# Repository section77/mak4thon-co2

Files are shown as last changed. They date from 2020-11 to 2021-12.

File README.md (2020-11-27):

# Klassenzimmer Modul

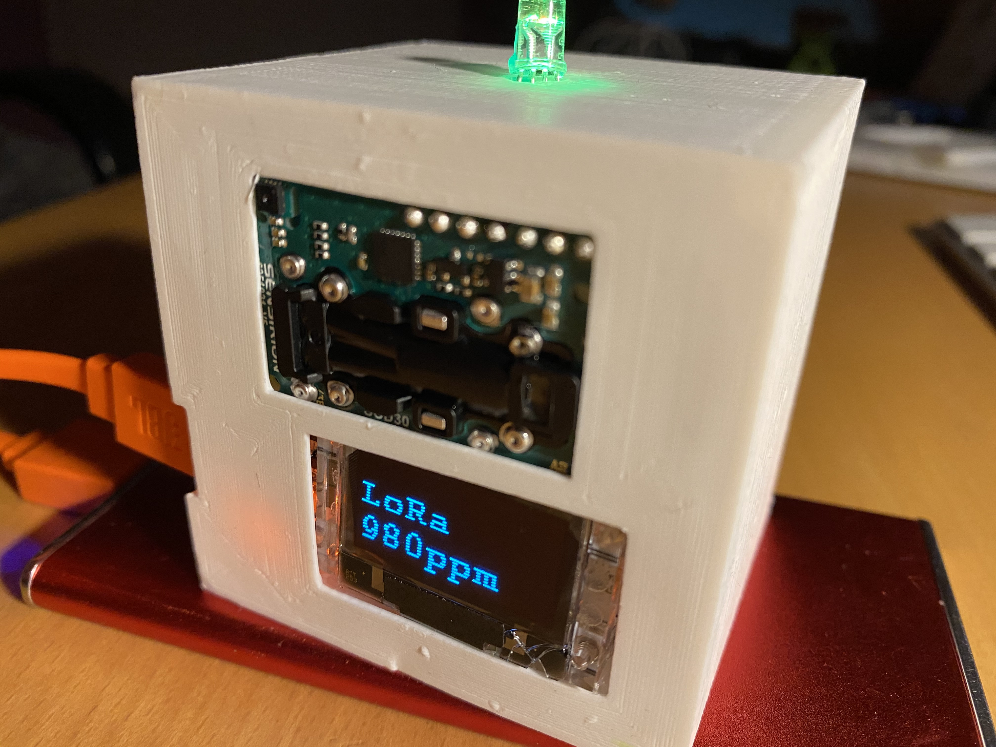
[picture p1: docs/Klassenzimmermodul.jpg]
Klassenzimmer Modul


## Hardware:
- Heltec WiFi Lora 32 V2 mit OLED
- SCD30 CO2 Sensor
- RGB LED zur Signalisierung der CO2 Konzentration (rot, gelb, grün)
- OLED Display zur numerischen Anzeige CO2 Konzentration, Luftfeuchtigkeit und Temperatur sowie WiFi oder LoRa Status

## Funktion:
  CO2, Luftfeuchtigkeit und Temperatur aus dem SCD30 lesen und
  auf dem OLED darstellen. Grenzwertüberschreitung an der RGB LED anzeigen.
  Digitale Werte über WiFi nach volkszaehler.org schreiben oder über LoRa
  an eine LoRa-Wifi-Bridge senden.

# LoRa-WiFi-Bridge

# Hardware:
- ESP32 WROOM32
- RFM9x LoRa 868/915MHz

# Funktion:
- Werte über LoRa entgegennehmen und über WiFi weiterleiten

# Server Installation unter Ubuntu

Wir liefern eine vorkonfigurierte Umgebung unter Ubuntu. Um den Server aufzusetzen (Installation von Docker und Docker-Compose und weiterer Abhängigkeiten) kann unsere [Setup-Anleitung](SETUP-Server.md) verwendet werden.

# volkszaehler.org

- Von einem Teammitglied betrieben
- freie Software, kann auch z.B. auf einem RPi betrieben werden
- Ursprünglich für Smartmeter (Stromverbrauch, Heizung usw.) gedacht
- keine Anmeldung, Schreib- und Lesezugriff erfolgt über UUIDs

# Datenfluss

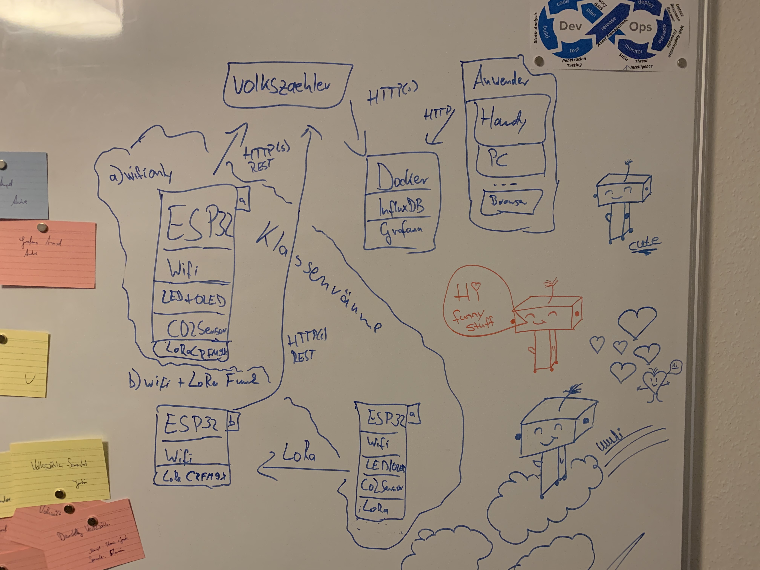
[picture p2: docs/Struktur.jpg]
Struktur


Die Klassenzimmermodule erfassen die Temperatur, Luftfeuchtigkeit und CO2 Konzentration.
Grenzwertüberschreitungen werden an der RGB LED angezeigt, zudem alle Werte auf dem OLED dargestellt.

Besteht eine WLAN Verbindung, werden die erfassten Daten direkt per http auf volkszaehler.org hinzugefügt.
Besteht keine Verbindung, so werden die Werte über LoRa gesendet.

Die LoRa-WiFi-Bridge nimmt in dem Fall die Werte über LoRa entgegen und gibt diese über http weiter

# Grafana Docker Setup

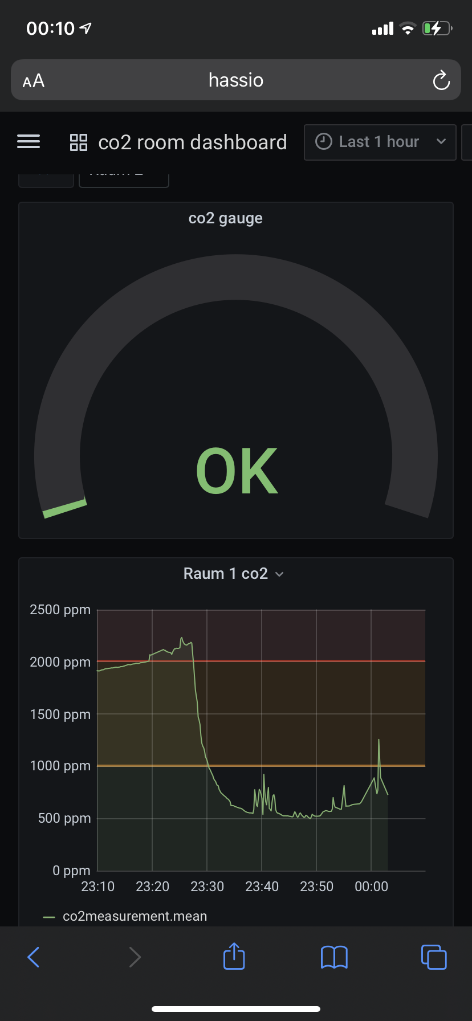
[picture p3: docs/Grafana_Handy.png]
Grafana auf dem Smartphone
;

Mittels Grafana lassen sich die Messwerte sehr anschaulich visualisieren. Die Werte können als Momentanwerte
oder als zeitlicher Verlauf dargestellt werden. Grafana lässt sich auf einem normalen PC im Browser nutzen oder
auch auf einem Tablet oder Smartphone.

Grafana bezieht die Daten aus volkszaehler.org und stellt diese dann dar. 

Die Installation von Grafana kann auch einem PC oder einem Server erfolgen. Die hierfür benötigten Dateien befinden
sich im Unterordner Visualisierung.

Current implementation uses volkszaehler for gathering sensor data.

Configure Polling settings in poll-volkszaehler/php/config. See [README](poll-volkszaehler/README.md).

```
docker-compose up
```

# on co2

co2 is measured in ppm (parts per million)

data ranges from 250 ppm (normal ambient air) - > 40.000 ppm (toxic) 
https://www.kane.co.uk/knowledge-centre/what-are-safe-levels-of-co-and-co2-in-rooms

sanitary safe levels of co2 in rooms:

| co2 concentration (ppm) | sanitary rating | suggestion |
|:---:|:---:|:---:|
| < 1000 | uncritical | no actions needed |
| 1000–2000 | noticeable | ventilation needed |
| >2000 | unacceptable | additional ventilation measures needed |

source: https://www.umweltbundesamt.de/sites/default/files/medien/pdfs/kohlendioxid_2008.pdf

in regards to covid. co2 concentration over ambient environment concentration. (e.g. green = 410+350 - 410+549 =~ green)

| # | co2 concentration (ppm) | color |
|:-----:|:---:|:---:|
| IDA 1 |  350 - 549 | green |
| IDA 2 |  550 – 1049 | light green |
| IDA 3 | 1050 - 1549 | yellow |
| IDA 4 | > 1550 | red |

source: ["Risikobewertung von virenbeladenen Aerosolen anhand der CO2-Konzentration"](co2-colors.png)
Autoren: Anne Hartmann, Martin Kriegel
Technische Universität Berlin, Hermann-Rietschel-Institut
DOI: http://dx.doi.org/10.14279/depositonce-10361

# Weitere Ideen, die es nicht in den Prototypen geschafft haben

## Gehäuse
- Halterungen für die Bauteile (im Prototyp nur geklebt)
- kompakter durch passende Leitungslängen oder Platine
- Gehäuse für die LoRa-Wifi-Bridge
- für Grundschulen eine andere Gehäusevariante: Ein 3D gedrucktes Haus mit Fenster. Ein Servo öffnet die Fenster bei überschreiten des Grenzwerts (anstelle einer roten LED)

## Elektronik
- Einbau eines LiPo-Akkus → mobiler Betrieb; Controller hat schon Laderegler integriert

## Software
- ESPs in den Klassenräumen:
  * Lineare Regression über die letzten 5min C02 Werte um die voraussichtliche Zeit bis zum Überschreiten des Grenzwertes zu berechnen.
  * Abfallen der CO2 Konzentration erkennen und den asymptotischen Verlauf erkennen. Empfehlung zum Schließen der Fenster geben, wenn Änderungsrate unter Schwellwert fällt. Hintergrund Energiesparen, nur so lange Lüften wie auch Sinn macht.

## Rollout
- automatische Erzeugung von UUIDs, die das Flashen mit identischen Binaries erlaubt (vzero?)

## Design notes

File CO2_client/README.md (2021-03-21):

# Software für die Module in den Klassenräumen

Siehe auch den Header von CO2-api.ino

## Konfiguration:

Die zwei .h.template kopieren, in .h umbenennen und die Zugangsdaten eintragen oder so lassen, falls kein WLAN vorhanden ist.
Dann wird automatisch LoRa verwendet.

## Verdrahtung:
  ../docs/CO2\_Sender\_ESP32_LoRa.pdf

## Links:
  Heltec repo mit Schaltplänen PinoutDiagram usw. -> Sehr zu empfehlen
  https://github.com/Heltec-Aaron-Lee/WiFi_Kit_series.git

## Versorgungsspannung oder Batteriespannung lesen?

In WiFi_LoRa_32_V2(433,470-510).PDF sieht man, dass an Pin13 ein Spannungsteiler
von VBat hängt, wahrscheinlich gedacht um die Batteriespannung zu überwachen.
  http://community.heltec.cn/t/heltec-esp32-wifi-kit-example-to-read-a-voltage/115/2

Aber Pin 13 hängt auf ADC2 und den kann man nicht zusammen mit WiFi verwenden:
  "ADC2 is used by the Wi-Fi driver. Therefore the application can only use ADC2 when the Wi-Fi driver has not started."
  https://docs.espressif.com/projects/esp-idf/en/latest/esp32/api-reference/peripherals/adc.html

Deshalb gibt es von dem heltec Modul eine Version V2.1 wo der Pin von 13 auf 37 (ADC1) geändert wurde:
  http://community.heltec.cn/t/heltec-wifi-lora-v2-battery-management/147/18

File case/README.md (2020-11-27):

front
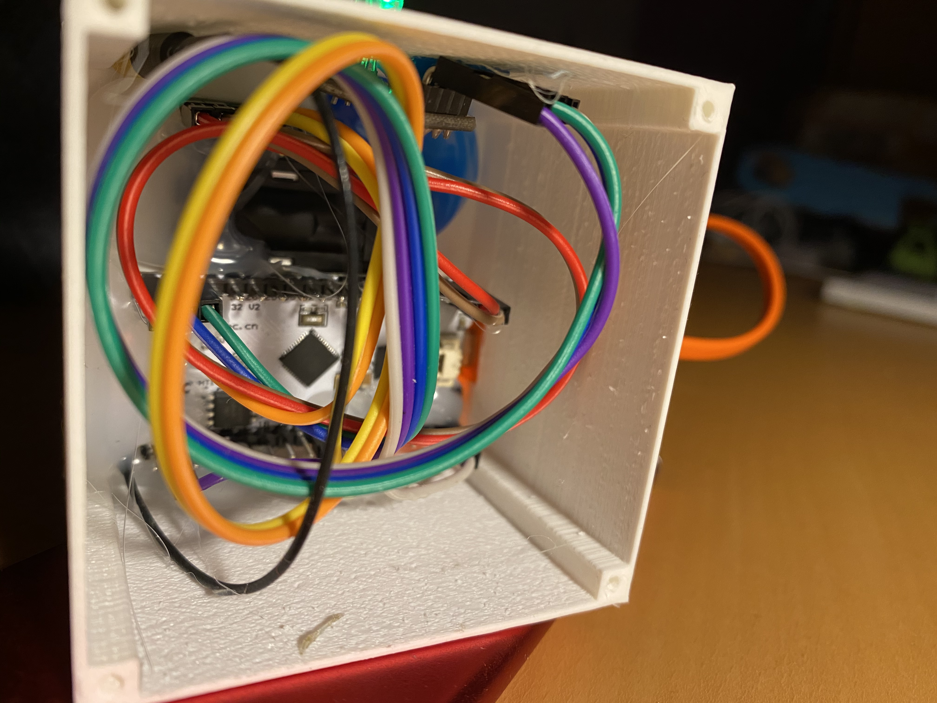
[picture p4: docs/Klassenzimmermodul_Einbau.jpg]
back


You can recreate the .stl with https://www.openscad.org/

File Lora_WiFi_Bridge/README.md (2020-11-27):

This directory contains Arduino firmware to capture LoRa from an sender
and forwards via Wifi and TCP to volkszaehler or the nodejs middleware.

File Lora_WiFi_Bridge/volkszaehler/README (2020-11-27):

Software für die Lora-Wifi Brücke zu Volkszähler (nur einmal, benötigt WLAN Zugang)

Siehe auch den Header von Lora_WiFi_Bridge.ino

Konfiguration:
  Siehe auch den Header der .ino
  Die zwei .h.template kopieren, in .h umbenennen und die Zugangsdaten eintragen.

Verdrahtung:
  ../../doc/CO2-Empfänger.jpg

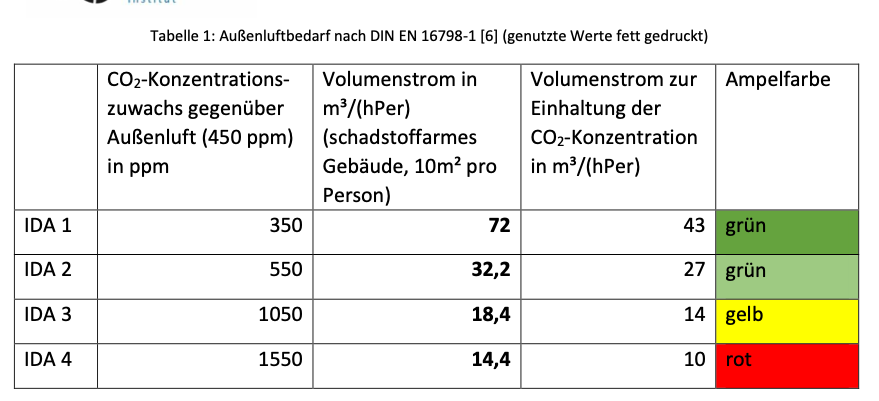
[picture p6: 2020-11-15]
docs/co2-colors.png

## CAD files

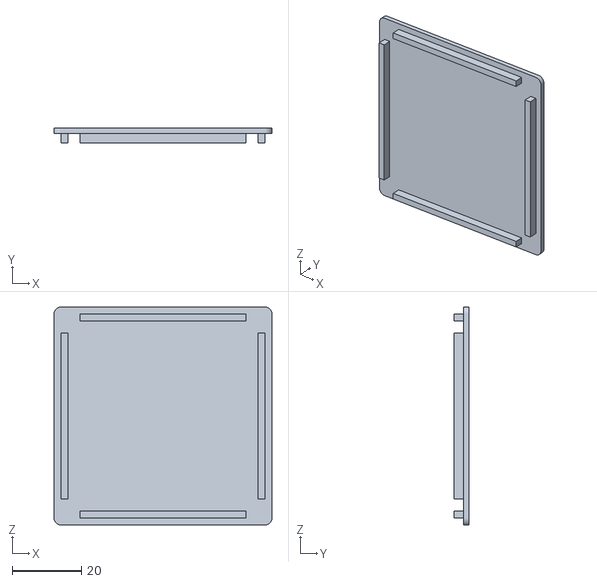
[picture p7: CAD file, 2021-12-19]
case/back.stl
63.0 x 4.25 x 63.0

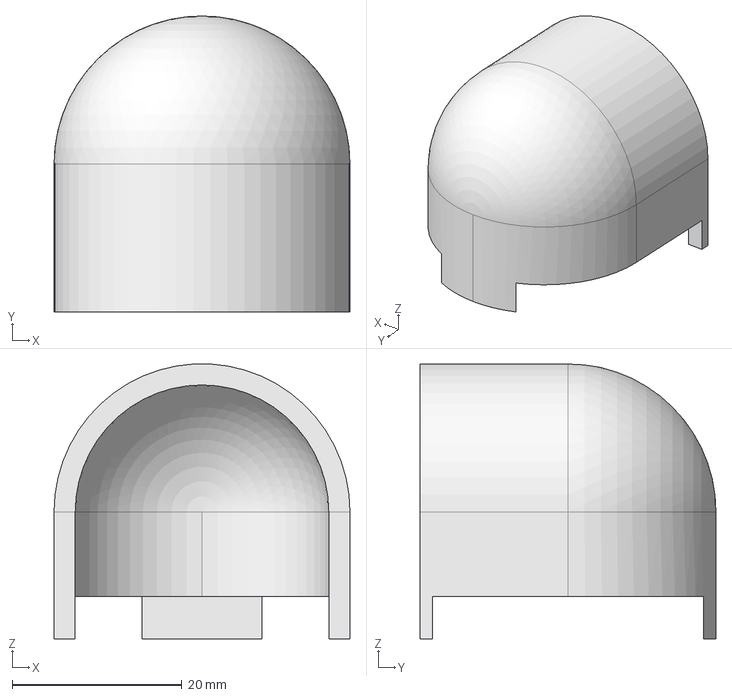
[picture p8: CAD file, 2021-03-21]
case/LED_Haube.FCStd
34.9 x 34.9 x 32.4 mm

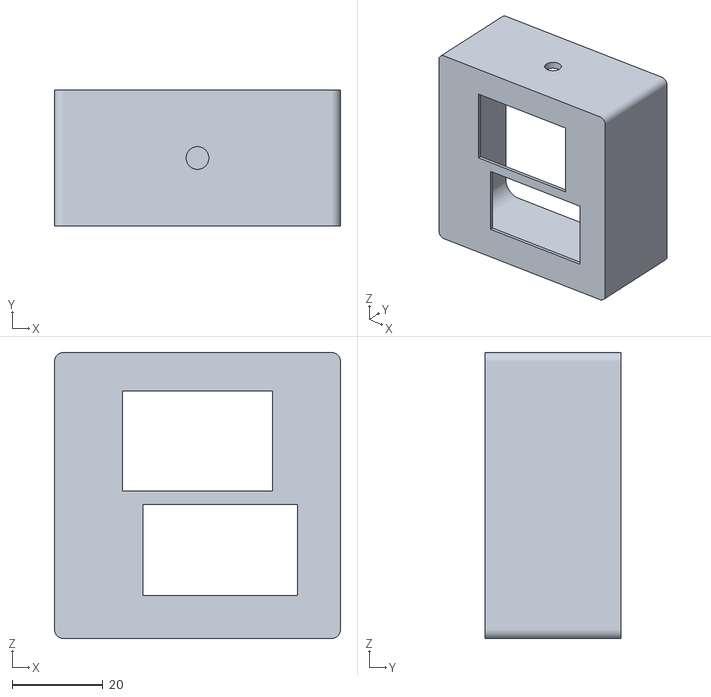
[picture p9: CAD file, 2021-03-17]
case/case.stl
63.0 x 30.0 x 63.0

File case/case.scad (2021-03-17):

$fn=100;

case=true;
back=true;

screwholes=false;  // optional; only needed if you want the case to be very close (or maybe unopenable without a screwdriver)

width=60;
height=60;
depth=30;

wall=1;

// display
display_width=34;
display_height=20;
display_x=5;
display_z=-12;

// sensor
sensor_width=33;
sensor_height=22;
sensor_x=0;
sensor_z=12;

// usb connector
usb_width=10;
usb_height=12;
usb_depth=8;
usb_x=-33;
usb_y=-depth/2+3;
usb_z=-11;

// LED
led_diameter=5;
led_z=height/2;

if (case) {
  
    difference() {
      union() {
        difference() { // case
          minkowski() {
            cube([width-wall,depth-1,height-wall], center=true);  // body
            rotate([90,0,0]) cylinder(r=2,h=1, center=true);
          } // rounded edge
          
          translate ([0,wall,0]) cube([width-wall,depth,height-wall], center=true); // inner space
          translate([display_x,-depth/2,display_z]) cube([display_width, 10, display_height], center=true); // display
          translate([sensor_x,-depth/2,sensor_z]) cube([sensor_width, 10, sensor_height], center=true); // sensor
          translate([usb_x,usb_y+wall*2,usb_z]) rotate([90,0,0]) cube([usb_width, usb_height, usb_depth], center=true); // usb connector
          translate([0,0,led_z]) cylinder(d=led_diameter, h=wall*4, center=true); // led
        }
        translate([(width/2-wall*1.5), 0, (height/2-wall*1.5)]) corner();
        translate([-(width/2-wall*1.5), 0, -(height/2-wall*1.5)]) rotate([0,180,0]) corner();
        translate([-(width/2-wall*1.5), 0, height/2-wall*1.5]) rotate([0,-90,0]) corner();
        translate([width/2-wall*1.5, 0, -(height/2-wall*1.5)]) rotate([0,90,0]) corner();
      }
      /*#translate([30,0,0]) cube([100,100,100], center=true); // block for print debugging
      #translate([0,0,30]) cube([100,100,100], center=true); // block for print debugging
      #translate([0,-50,0]) cube([100,100,100], center=true); // block for print debugging*/
    }
    
}

module corner() { // corner blocks for screws
  width=5;
  hole=2.5;
  difference() {
    translate([-1,0,-1]) cube([width, depth, width], center=true);
    if (screwholes) {
      translate([0,1,0]) rotate([90,0,0]) cylinder(d=hole, h=depth, center=true); // only if you want screwholes
    } else {
      translate([-3.9,1,-3.9]) rotate([90,0,0]) cylinder(d=10, h=depth, center=true);
    }
  }
}

if (back) {
  difference() {
    hole=3.5;
    translate([0,depth,0]) union() {
      minkowski() {
        cube([width-wall,wall/2,height-wall], center=true); // back plate
        rotate([90,0,0]) cylinder(r=2,h=1, center=true);
      } // rounded edge
      translate([0,-wall*2,height/2+wall/2-wall*2]) cube([width-12,wall*3,wall*2], center=true); // top
      translate([0,-wall*2,-(height/2-wall*1.5)]) cube([width-12,wall*3,wall*2], center=true); // bottom
      translate([width/2-wall*1.5,-wall*2,0]) rotate ([0,90,0]) cube([width-12,wall*3,wall*2], center=true); // left
      translate([-(width/2-wall*1.5),-wall*2,0]) rotate ([0,90,0])  cube([width-12,wall*3,wall*2], center=true); // right   
    };
    if (screwholes) { // only if you want screwholes
      translate([width/2-wall*1.5,depth,height/2-wall*1.5]) rotate ([90,0,0]) cylinder(d=hole,h=10, center=true);
      translate([-(width/2-wall*1.5),depth,-(height/2-wall*1.5)]) rotate ([90,0,0]) cylinder(d=hole,h=10, center=true);
      translate([-(width/2-wall*1.5),depth,height/2-wall*1.5]) rotate ([90,0,0]) cylinder(d=hole,h=10, center=true);
      translate([width/2-wall*1.5,depth,-(height/2-wall*1.5)]) rotate ([90,0,0]) cylinder(d=hole,h=10, center=true);
      /*#translate([30,0,0]) cube([100,100,100], center=true); // block for print debugging
      #translate([0,0,30]) cube([100,100,100], center=true); // block for print debugging
      #translate([0,-50,0]) cube([100,100,100], center=true); // block for print debugging*/
    };
  };
}

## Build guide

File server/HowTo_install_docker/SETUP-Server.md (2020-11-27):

# Setup Ubuntu Server

Folge am besten der aktuellen Originalanleitung unter https://docs.docker.com/engine/install/ubuntu/

Zum Zeitpunkt des Schreibens (und so in Verwendung in [setup-ubuntu-x86.sh](setup-ubuntu-x86.sh)):

## OS requirements

Um Docker Engine zu installieren, benötigst du eine dieser 64-bit Versionen von Ubuntu:

Ubuntu Focal 20.04 (LTS)
Ubuntu Bionic 18.04 (LTS)
Ubuntu Xenial 16.04 (LTS)

# Alte Version(en) deinstallieren

für den Fall dass bereits irgendetwas über das standard apt repository installiert wurde:

    $ sudo apt-get remove docker docker-engine docker.io containerd runc

# Installation via docker repository

1. ) Update the apt package index and install packages to allow apt to use a repository over HTTPS:

```
    $ sudo apt-get update
    $ sudo apt-get install \
        apt-transport-https \
        ca-certificates \
        curl \
        gnupg-agent \
        software-properties-common
```

2. Add Docker’s official GPG key:

```
    $ curl -fsSL https://download.docker.com/linux/ubuntu/gpg | sudo apt-key add -
```

Verify that you now have the key with the fingerprint 9DC8 5822 9FC7 DD38 854A  E2D8 8D81 803C 0EBF CD88, by searching for the last 8 characters of the fingerprint.

```

$ sudo apt-key fingerprint 0EBFCD88

pub   rsa4096 2017-02-22 [SCEA]
      9DC8 5822 9FC7 DD38 854A  E2D8 8D81 803C 0EBF CD88
uid           [ unknown] Docker Release (CE deb) <docker@docker.com>
sub   rsa4096 2017-02-22 [S]
```

3. Use the following command to set up the stable repository. To add the nightly or test repository, add the word nightly or test (or both) after the word stable in the commands below. Learn about nightly and test channels.

x86/ amd64 (normale PCs):

```
    $ sudo add-apt-repository \
    "deb [arch=amd64] https://download.docker.com/linux/ubuntu \
    $(lsb_release -cs) \
    stable"
```

Raspberry: https://wiki.debian.org/RaspberryPi4

armhf (raspberryPI 3/4 mit Raspbian):

```
    $ sudo add-apt-repository \
    "deb [arch=armhf] https://download.docker.com/linux/ubuntu \
    $(lsb_release -cs) \
    stable"
```

arm64 (Raspberry PI mit Ubuntu und arm64 image)

```
    $ sudo add-apt-repository \
    "deb [arch=arm64] https://download.docker.com/linux/ubuntu \
    $(lsb_release -cs) \
    stable"
```

## Docker Pakete installieren

sudo apt-get update
sudo apt-get install docker-ce docker-ce-cli containerd.io

## install docker compose

Anleitung hier: https://docs.docker.com/compose/install/

```
sudo curl -L "https://github.com/docker/compose/releases/download/1.27.4/docker-compose-$(uname -s)-$(uname -m)" -o /usr/local/bin/docker-compose
sudo chmod +x /usr/local/bin/docker-compose
```

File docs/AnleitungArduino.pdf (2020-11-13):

Anleitung Arduino.exe

Damit ihr euren Mikrokontroller mit einer Software programmieren könnt, stellen wir euch die Arduino IDE als ZIP-Ordner zur Verfügung. Diesen Ordner findet ihr auf der SCIEBO in dem Ordner „Dateien zum Download“. Dort könnt ihr den Ordner herunterladen und anschließend auf eurem Computer entpacken.

Wenn ihr dies gemacht habt, müsste eure Ordnerstruktur wie auf dem folgenden Bild gezeigt aussehen.

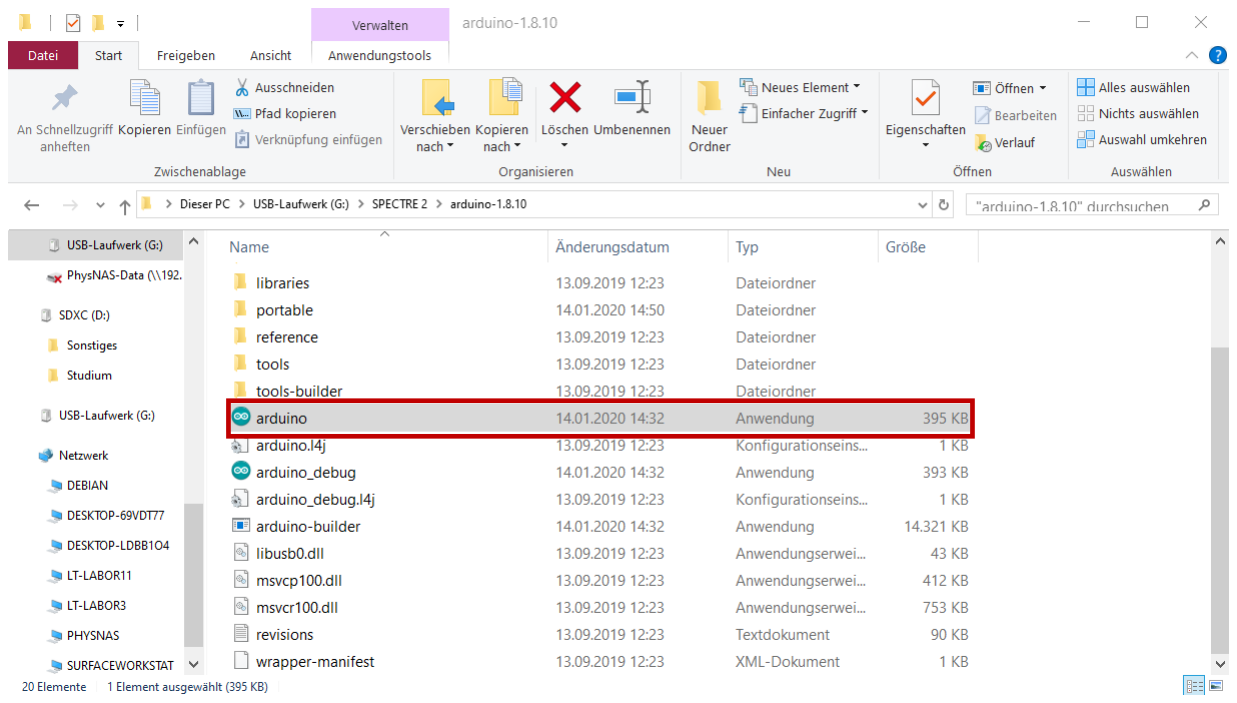
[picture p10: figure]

Die Arduino IDE kann durch das Ausführen der arduino.exe (Roter Kasten) geöffnet werden.

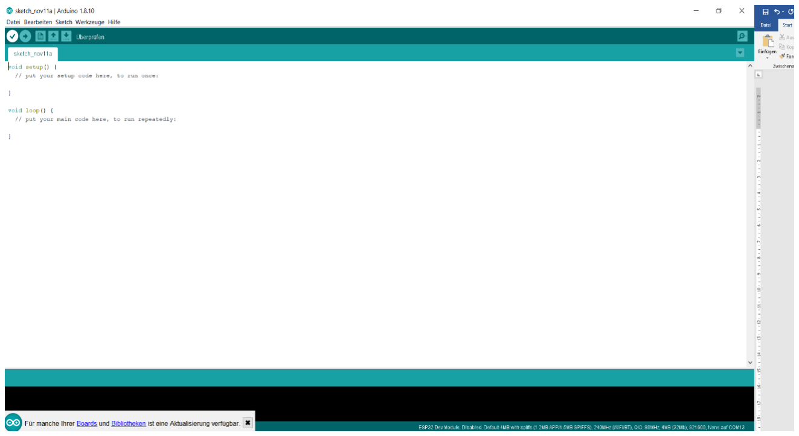
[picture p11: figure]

Jetzt könnt ihr das Fenster mit eurem Quellcode füllen. Damit ihr zum Beispiel eure Sensoren ansteuern könnt, müsst ihr einige Bibliotheken einbinden. Die Bibliotheken, welche zur Verwendung des ESP32 benötigt werden sind schon in eurem ZIP-Ordner hinterlegt, sowie manch andere

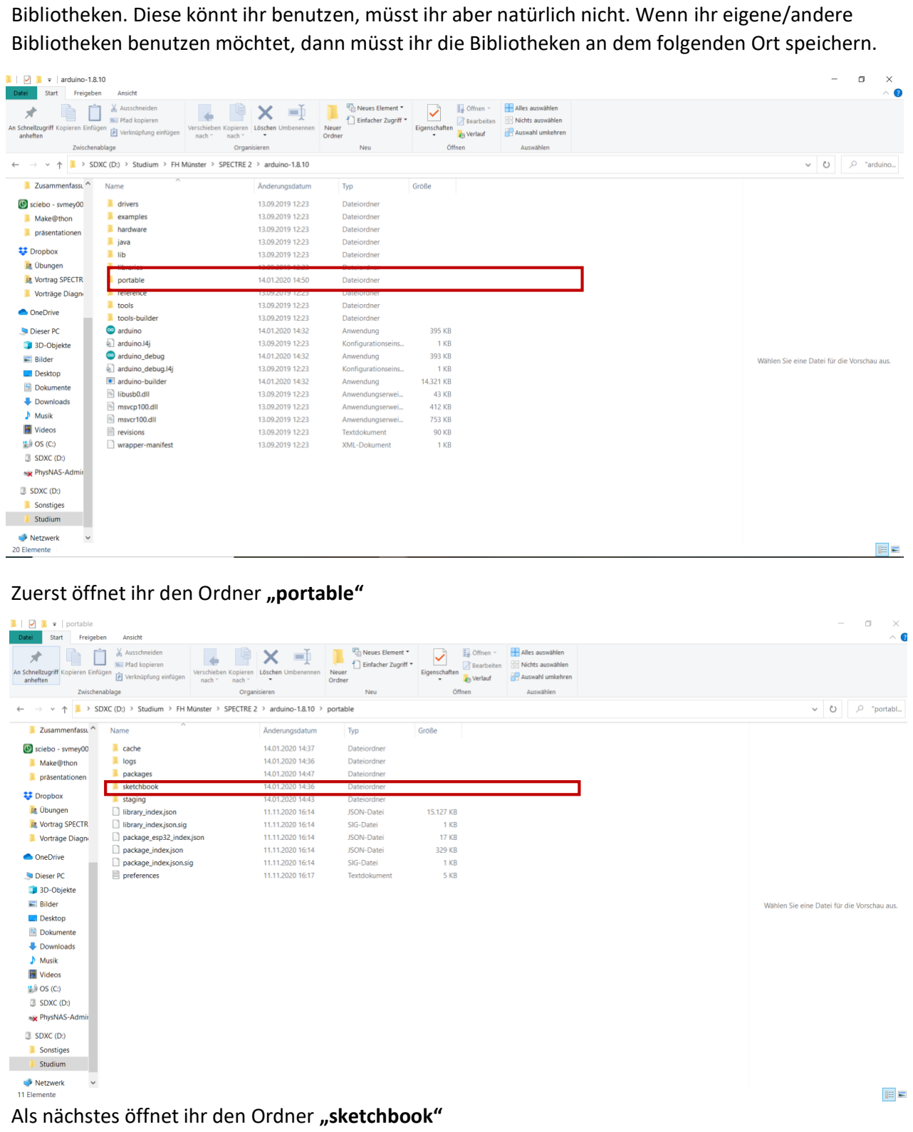
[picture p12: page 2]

Bibliotheken. Diese könnt ihr benutzen, müsst ihr aber natürlich nicht. Wenn ihr eigene/andere Bibliotheken benutzen möchtet, dann müsst ihr die Bibliotheken an dem folgenden Ort speichern.

Zuerst öffnet ihr den Ordner „portable“

Als nächstes öffnet ihr den Ordner „sketchbook“

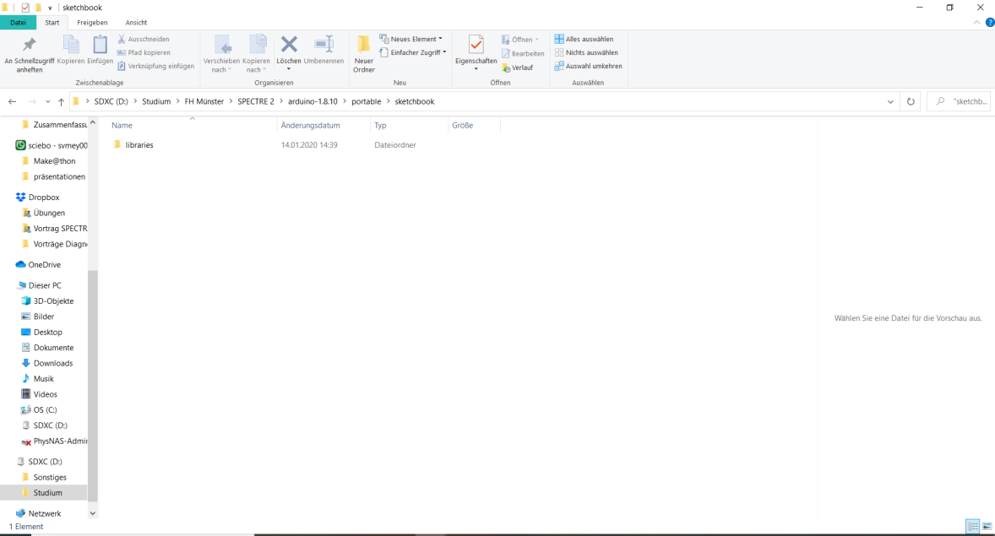
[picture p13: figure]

Dann seht ihr den Ordner „libraries“ . In diesem Ordner müssen all eure Bibliotheken abgespeichert werden. In dem nachfolgenden Bild seht ihr eine kleinen Ausschnitt von meinen Bibliotheken.

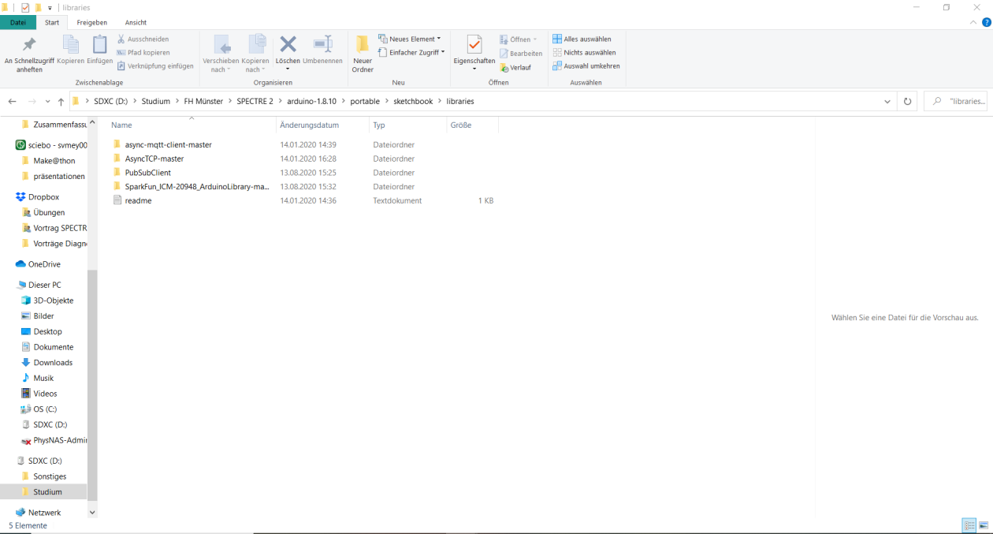
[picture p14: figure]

Als nächstes zeige ich euch, wie ihr ein Programm auf euer Modul übertragen könnt.

Damit dies funktioniert, müssen bei Arduino zwei Einstellungen vorgenommen werden.

- Zuerst muss der Microcontroller eingestellt werden, welcher benutzt wird. Dazu werden die im folgenden Bild dargestellten Schritte durchgeführt.
- Werkzeug auswählen
- Board …
- In dem Paket befindet sich ein ESP32 Dev Module und ein Heltec WiFi LoRa 32(V2) Modul. Das entsprechende Modul, welches ihr bespielen wollt, muss in der Arduino IDE ausgewählt werden.

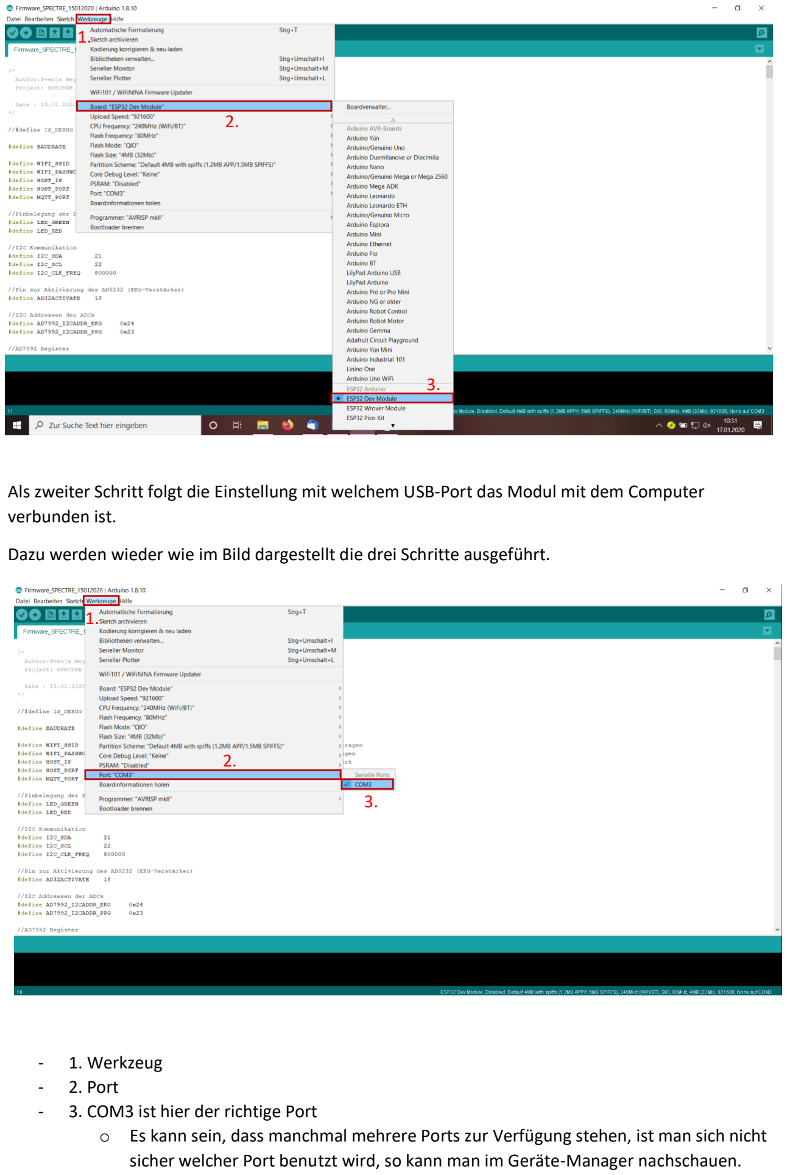
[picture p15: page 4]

Als zweiter Schritt folgt die Einstellung mit welchem USB-Port das Modul mit dem Computer verbunden ist.

Dazu werden wieder wie im Bild dargestellt die drei Schritte ausgeführt.

- 1. Werkzeug
- 2. Port
- 3. COM3 ist hier der richtige Port
- Es kann sein, dass manchmal mehrere Ports zur Verfügung stehen, ist man sich nicht sicher welcher Port benutzt wird, so kann man im Geräte-Manager nachschauen.

1.

2.

3.

1.

2.

3.

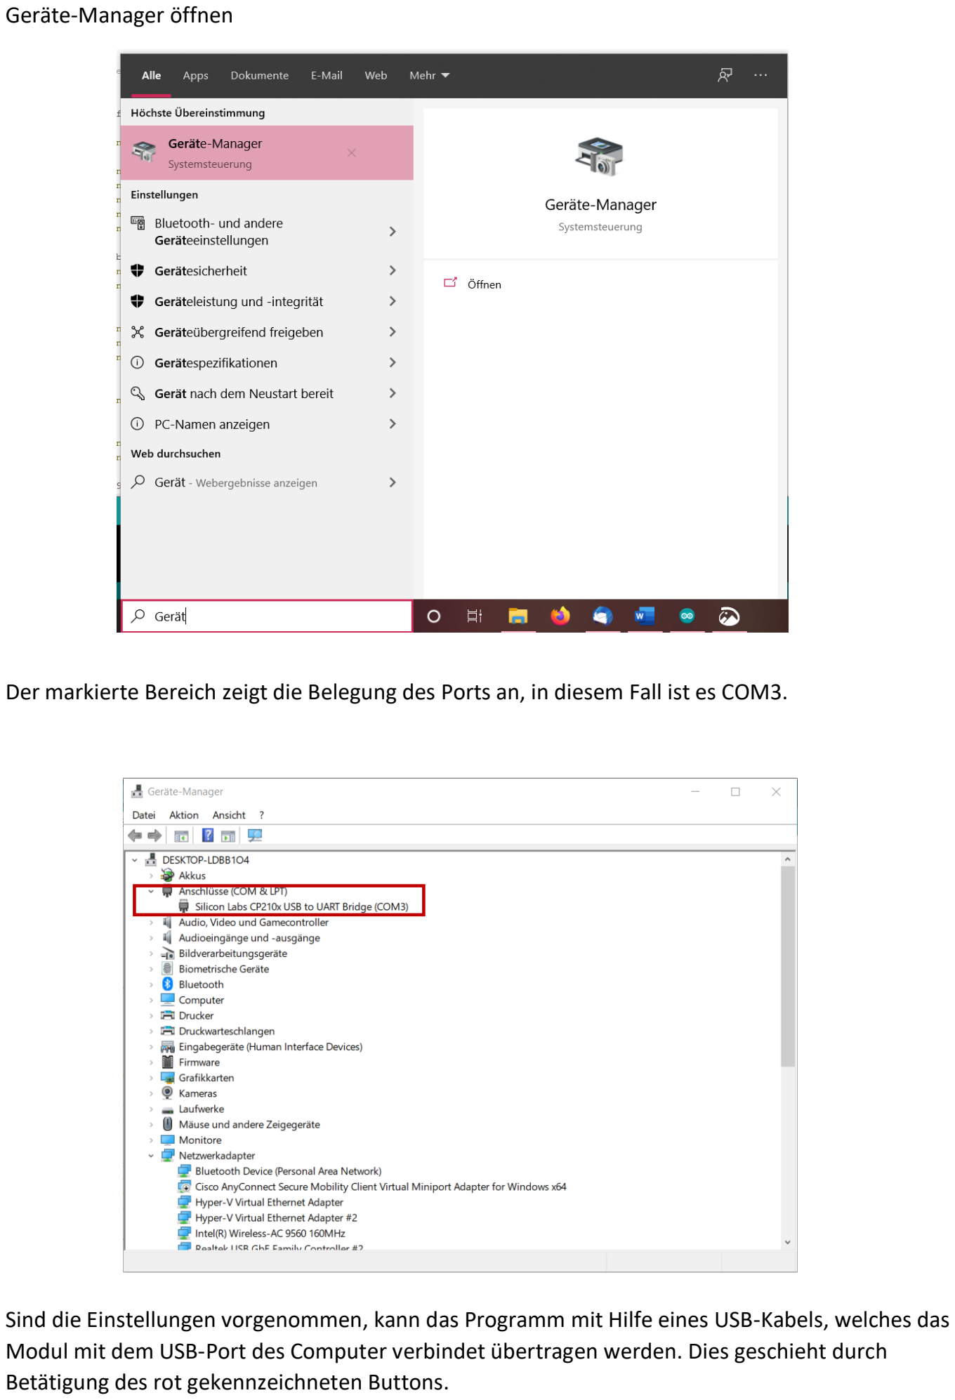
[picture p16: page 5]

Geräte-Manager öffnen

Der markierte Bereich zeigt die Belegung des Ports an, in diesem Fall ist es COM3.

Sind die Einstellungen vorgenommen, kann das Programm mit Hilfe eines USB-Kabels, welches das Modul mit dem USB-Port des Computer verbindet übertragen werden. Dies geschieht durch Betätigung des rot gekennzeichneten Buttons.

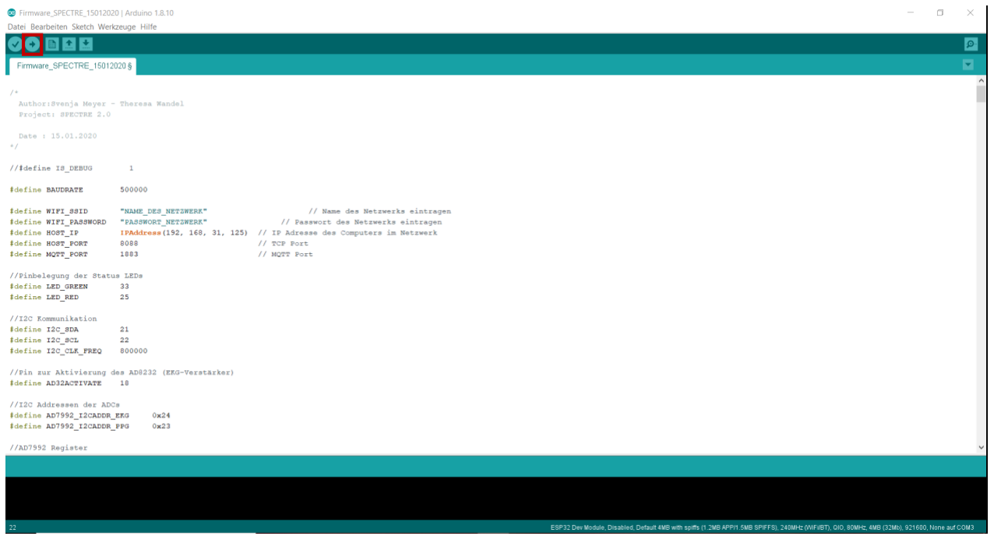
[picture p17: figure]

Das war es auch schon mit der kleinen Einführung in die Arduino IDE.

## Viel Spaß beim Programmieren!!

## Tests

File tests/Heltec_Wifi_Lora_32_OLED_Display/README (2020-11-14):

Hardwareverbindungen über I2C zum OLED Modul:

  OLED_SDA -- GPIO4
  OLED_SCL -- GPIO15
  OLED_RST -- GPIO16

Die Seite https://www.hackerspace-ffm.de/wiki/index.php?title=Heltec_Wifi_LoRa_32
zählt ein paar Libs für das Display auf sowie die Konfiguration.

=== squix78 ssd1306.h neu: ThingPulse / esp8266-oled-ssd1306 ===

https://github.com/ThingPulse/esp8266-oled-ssd1306
Kann über den Bibliotheksverwalter installiert werden "ESP8266 and ESP32 Oled Driver for SSD1306 display"

Wird im DisplayWifiTest verwendet aber ich bekomme nicht den SCD30 und das Display gleichzeitig ans laufen
Siehe https://github.com/ThingPulse/esp8266-oled-ssd1306/issues/235

Scheint ein bekanntes Problem zu sein, dass mit der Lib nicht mehrere I2C Slaves gleichzeitig können

=== Adafruit SSD1306 ===

Die sind bereits von anfang an installiert.
Ich finde da die Einstellung für die I2C Adresse, aber nicht wo man SCL und SDA anpassen kann

=== U8g2_u8x8 ===

Das läuft gut, siehe U8g2_u8x8/GraphicsTest/GraphicsTest.ino

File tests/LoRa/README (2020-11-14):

Wir haben 2x LoRa Hardware bekommen:

- RFM9x LoRa 868/915MHz: https://www.adafruit.com/product/3072
- WiFi Lora 32 V2 hat auch LoRa: https://heltec.org/project/wifi-lora-32/

Libs:
  Ich habe am Freitag Abend die "LoRa" Lib 0.7.2 von Sandeep Mistry
  aus dem arduino Bibliotheksverwalter ausprobiert, weil sie ca. 800 stars auf github hat.

  Settings für das "WiFi Lora 32 V2" Board:
    LoRa.setPins(18, 14, 26); // set CS, reset, IRQ pin

  Adafruit listet libs auf:
  - LowPowerLab's RFM69 Library https://github.com/LowPowerLab/RFM69
  - AirSpayce's Radiohead library http://www.airspayce.com/mikem/arduino/RadioHead/

  Adafruit empfiehlt im Tutorial die Radiohead lib:
  von http://www.airspayce.com/mikem/arduino/RadioHead/ das Zip laden und installieren

  Der Treiber für unseren LoRa Chip ist der "RH_RF95"

=== LoRa Server: ESP32 Dev Module (az-delivery) mit Adafruit RFM9x Modul === 

ESP32 WROOM (ohne Display) verdrahtet wie in ../official-files/CO2-Empfänger.JPG zu sehen

https://learn.adafruit.com/adafruit-rfm69hcw-and-rfm96-rfm95-rfm98-lora-packet-padio-breakouts/pinouts

Die Verdrahtung als Text:

G0   - violett - G2
SCK  - braun   - G18
MISO - orange  - G19
MOSI - grau    - G23
CS   - grün    - G5
RST  - blau    - G14

#define RFM95_RST     14
#define RFM95_CS      5
#define RFM95_INT     2

=== Lora Client: WiFi Lora 32 V2 ===

schon intern verdrahtet:

   CS  - G18
   RST - G14
   IRQ - G26

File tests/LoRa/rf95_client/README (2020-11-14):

Beispiel rf92_client von http://www.airspayce.com/mikem/arduino/RadioHead/
an das adafruit RFM9x Modul angepasst

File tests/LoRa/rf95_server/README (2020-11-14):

RadioHead Beispielcode,
ESP32 az-delivery mit externem Arduino RFM9x Modul,
siehe auch ../README

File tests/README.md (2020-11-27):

This directory contains code snippets for testing hardware or a general playground

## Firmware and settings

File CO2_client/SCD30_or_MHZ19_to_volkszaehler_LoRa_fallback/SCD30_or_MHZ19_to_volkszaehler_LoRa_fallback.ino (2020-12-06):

/*
 * Verwendete Hardware:
 *  - Heltec WiFi Lora 32 V2
 *  - SCD30 oder MHZ19
 *  - RGB LED
 *
 * Funktionen:
 *  - CO2, Luftfeuchtigkeit und Temperatur aus dem SCD30/MHZ19 lesen
 *  - auf dem OLED darstellen
 *  - Grenzwertüberschreitung an der RGB LED anzeigen
 *  - Werte über WiFi nach volkszaehler.org schreiben
 *  - Werte über LoRa senden
 *  - Debugging über Serial 115200
 *
 * Verwendete, zusätzliche Bibliotheken:
 *  - U8g2_u8x8 für OLED (über Bibliotheksverwaltung)
 *  - SparkFun_SCD30_Arduino_Library (über Bibliotheksverwaltung) https://github.com/sparkfun/SparkFun_SCD30_Arduino_Library
 *  - MH-Z19 by Jonathan Dempsey (über Bibliotheksverwaltung) https://github.com/WifWaf/MH-Z19
 *  - Radiohead für LoRa (Zip Download, installieren) http://www.airspayce.com/mikem/arduino/RadioHead/
 */

//#define USE_VOLKSZAEHLER
#define USE_NEW_POST_JSON
//#define USE_LORA

#define USE_SCD30
//#define USE_MHZ19

/*************************************************************************************/

#include <Arduino.h>
#include <U8x8lib.h>

#ifdef U8X8_HAVE_HW_SPI
#include <SPI.h>
#endif
#ifdef U8X8_HAVE_HW_I2C
#include <Wire.h>
#endif

#include <Wire.h>
#include <Arduino.h>

#include <WiFi.h>
#include <WiFiMulti.h>

#ifdef USE_LORA
#include <RH_RF95.h>
RH_RF95 rf95(18, 26); // WiFi Lora 32 V2 (integriert)
#endif

#include <HTTPClient.h>
#include "wlan_settings.h"
//#include "uuids.h"
#include "module_token.h"

#ifdef USE_SCD30
#include "SparkFun_SCD30_Arduino_Library.h" //Click here to get the library: http://librarymanager/All#SparkFun_SCD30
SCD30 airSensor;
#endif

#ifdef USE_MHZ19
#include "MHZ19.h"
MHZ19 airSensor;
HardwareSerial mySerial(1);
#define RX_PIN 36
#define TX_PIN 2
#define BAUDRATE 9600
#endif

WiFiClient client;

// Hardwaresettings
const int ledPinRed = 17;     // Nico: 32
const int ledPinGreen = 12;   // Nico: 33
const int ledPinBlue = 13;    // Nico: 12

U8X8_SSD1306_128X64_NONAME_SW_I2C u8x8(/* clock=*/ 15, /* data=*/ 4, /* reset=*/ 16);

HTTPClient http;

void setup()
{
  Serial.begin(115200);
  Serial.println("CO2-api: Luftqualität messen, anzeigen und über Wifi oder LoRa weitergeben");

  // FIXME: Aus Sicherheitsgründen würde ich später nur die module_id auf Display und über Serial ausgeben
  Serial.printf("module_token = '%s'\n", module_token);
  Serial.printf("module_id = '%s'\n", module_id);

  Wire.begin();

#ifdef USE_SCD30
  if (airSensor.begin() == false)
    {
      Serial.println("Air sensor not detected. Please check wiring. Freezing...");
      while (1)
        ;
    }
#endif
#ifdef USE_MHZ19
  mySerial.begin(BAUDRATE, SERIAL_8N1, RX_PIN, TX_PIN);
  airSensor.begin(mySerial);
  airSensor.autoCalibration(); //auto calibration ON
#endif

  Serial.println("init WiFi network");
  WiFi.begin(ssid, wlan_password);
  Serial.println("Connecting to ");

  Serial.println(String(ssid));
  Serial.println("MAC: " + WiFi.macAddress());
  uint8_t max_wifi_retry = 10;  // entspricht 5s
  while (WiFi.status() != WL_CONNECTED && --max_wifi_retry)
    {
      delay(500);
      Serial.print(".");
    }
  if (max_wifi_retry)
    {
      Serial.println("");
      Serial.println("WiFi connected ");
      Serial.println(WiFi.localIP().toString());
    }
  else
    Serial.println("WiFi NOT connected (using LoRa fallback)");

  // RGB LED Ports konfigurieren
  pinMode(ledPinRed, OUTPUT);
  pinMode(ledPinGreen, OUTPUT);
  pinMode(ledPinBlue, OUTPUT);

  // OLED
  u8x8.begin();
  u8x8.setFont(u8x8_font_courB18_2x3_f);

  // Maximal 8 Zeichen module_id ausgeben
  {
    u8x8.setCursor(0, 2);
    // nach 8 Zeichen abschneiden
#define MAX_ID_LEN 8
    char tmp_mod_id[MAX_ID_LEN + 1];
    strncpy (tmp_mod_id, module_id, MAX_ID_LEN);
    tmp_mod_id[MAX_ID_LEN] = '\0';
    u8x8.print(tmp_mod_id);
  }

#ifdef USE_LORA
  // LoRa
  if (!rf95.init())
    Serial.println("init failed");
  // Defaults after init are 434.0MHz, 13dBm, Bw = 125 kHz, Cr = 4/5, Sf = 128chips/symbol, CRC on

  // You can change the modulation parameters with eg
  // rf95.setModemConfig(RH_RF95::Bw500Cr45Sf128);

  // The default transmitter power is 13dBm, using PA_BOOST.
  // If you are using RFM95/96/97/98 modules which uses the PA_BOOST transmitter pin, then
  // you can set transmitter powers from 2 to 20 dBm:
  //  rf95.setTxPower(20, false);
  // If you are using Modtronix inAir4 or inAir9, or any other module which uses the
  // transmitter RFO pins and not the PA_BOOST pins
  // then you can configure the power transmitter power for 0 to 15 dBm and with useRFO true.
  // Failure to do that will result in extremely low transmit powers.
  //  rf95.setTxPower(14, true);
#endif

  // allow reuse (if server supports it)
  http.setReuse(true);
}

void build_JSON (char *buf, size_t buflen, uint16_t co2, float temperature, float humidity)
{
  snprintf (buf, buflen, "{\"token\":\"%s\",\"id\":\"%s\",\"co2\":%u,\"temperature\":%.2f,\"humidity\":%.2f}", module_token, module_id, co2, temperature, humidity);
  buf[buflen - 1] = '\0';
}

uint8_t http_POST (const char *host, uint16_t port, const char *uri, const char *json)
{
  uint8_t ret = 0;
  http.begin(host, port, uri);

  // über www-form-urlencoded wäre auch möglich
  //http.addHeader("Content-Type", "application/x-www-form-urlencoded");
  //int httpCode = http.POST("token=555&co2=1234&temperature=24.5&humidity=44.5");

  http.addHeader("Content-Type", "application/json");


  int httpCode = http.POST(json);
  if(httpCode > 0)
    {
      // HTTP header has been send and Server response header has been handled
      // Serial.printf("[HTTP] POST... code: %d\n", httpCode);
    }
  else
    {
      Serial.printf("[HTTP] POST failed, error: %s\n", http.errorToString(httpCode).c_str());
      ret = -1;
    }
  http.end();
  return ret;
}

#ifdef USE_VOLKSZAEHLER
uint8_t push_http (const char* url, const char* UUID, float value)
{
  uint8_t ret = 0;

  char buf[300];
  snprintf (buf, 300, "%s%s.json?operation=add&value=%.2f", url, UUID, value);

  // debugging
  //Serial.println (buf);
  http.begin(buf);

  int httpCode = http.GET();

  // httpCode will be negative on error
  if(httpCode > 0)
    {
      // HTTP header has been send and Server response header has been handled
      //Serial.printf("[HTTP] GET... code: %d\n", httpCode);

      if(httpCode == HTTP_CODE_OK)
        ;//Serial.println("sent value via http");
      else
        ret = -1;
    }
  else
    {
      Serial.printf("[HTTP] GET failed, error: %s\n", http.errorToString(httpCode).c_str());
      ret = -1;
    }
  http.end();
  return ret;
}
#endif

#ifdef USE_LORA
void push_LoRa (const char* UUID, float value)
{
  // Messwert an die LoRa-WiFi-Bridge senden
  char value_buf[100];
  snprintf (value_buf, 100, "%s;%.2f", UUID, value);
  rf95.send((uint8_t *)value_buf, sizeof(value_buf));
  rf95.waitPacketSent();
  // Wir erwarten keine Antwort von der LoRa_WiFi_Bridge
  Serial.println("sent value via LoRa");
}
#endif

void push_value (const char* UUID, float value)
{
  // Debugging: Send to host in LAN
  // push_http ("http://192.168.10.116:8888", UUID, value);

#ifdef USE_VOLKSZAEHLER
  if(WiFi.status() == WL_CONNECTED)
    {
      if (push_http ("http://demo.volkszaehler.org/middleware/data/", UUID, value))
        {
          Serial.println("http failed, fallback to LoRa");
#ifdef USE_LORA
          push_LoRa (UUID, value);
#endif
        }
    }
  else
#endif
#ifdef USE_LORA
    push_LoRa (UUID, value);
#else
    ;
#endif
}

void pre ()
{
//  u8x8.clear();
//  u8x8.setCursor(0, 2);
//  if (WiFi.status() == WL_CONNECTED)
//    u8x8.print("WiFi");
//  else
//    u8x8.print("LoRa");

  u8x8.setCursor(0, 5);
}

void loop()
{
#ifdef USE_SCD30
  if (airSensor.dataAvailable())
#endif
    {
      uint16_t co2 = airSensor.getCO2();
      float temperature = airSensor.getTemperature();
      float humidity = 0;
#ifdef USE_SCD30
      humidity = airSensor.getHumidity();
#endif

      if(co2 > 1550)   // red Nico hat 2000 daraus gemacht
        {
          digitalWrite(ledPinRed, HIGH);
          digitalWrite(ledPinGreen, LOW);
          digitalWrite(ledPinBlue, LOW);
        }
      else if(co2 > 550)      // yellow Nico hat 1500 daraus gemacht
        {
          digitalWrite(ledPinRed, HIGH);
          digitalWrite(ledPinGreen, HIGH);
          digitalWrite(ledPinBlue, LOW);
        }
      else      // green
        {
          digitalWrite(ledPinRed, LOW);
          digitalWrite(ledPinGreen, HIGH);
          digitalWrite(ledPinBlue, LOW);
        }

      Serial.print("co2(ppm):");
      Serial.print(co2);

      Serial.print(" temp(C):");
      Serial.print(temperature, 1);

      Serial.print(" humidity(%):");
      Serial.print(humidity, 1);

      Serial.println();

      pre ();
      u8x8.printf("%4ippm ", co2);
      //push_value (uuid_co2, co2);
      delay (1000);

      pre ();
      u8x8.printf("%4.1f", temperature);
      u8x8.print("\xb0");
      u8x8.print("C ");
      //push_value (uuid_temp, temperature);
      delay (1000);

      pre ();
      u8x8.printf("%4.1f%%rH", humidity);
      //push_value (uuid_humidity, humidity);
      delay (1000);

#ifdef USE_NEW_POST_JSON
#define BUF_SIZE 200
      char buf[BUF_SIZE];
      build_JSON (buf, BUF_SIZE, co2, temperature, humidity);
      http_POST ("192.168.10.116", 4000, "/addSample", buf);
#endif

    }
#ifdef USE_SCD30
  else
    {
      Serial.println("Waiting for new sensor data");
      delay(1000);
    }
#else
  delay (5000);
#endif

}

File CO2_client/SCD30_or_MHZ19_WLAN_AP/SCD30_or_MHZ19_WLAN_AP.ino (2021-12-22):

/*
 * Verwendete Hardware:
 *  - Heltec WiFi Lora 32 V2
 *  - SCD30 oder MHZ19
 *  - RGB LED
 *
 * Funktionen:
 *  - CO2, Luftfeuchtigkeit und Temperatur aus dem SCD30/MHZ19 lesen
 *  - Grenzwertüberschreitung an der RGB LED anzeigen
 *  - Debugging über Serial 115200
 *  - Anzeige der Messwerte via WLAN (AP mode mit captive portal; die Seite wird automatisch angezeigt, sobald man sich 
 *    mit dem AP verbindet; ansonsten ist sie erreichbar unter http://192.168.1.1/)
 *  - Messintervall kann per measurement_interval eingestellt werden
 *
 * Verwendete, zusätzliche Bibliotheken:
 *  - SparkFun_SCD30_Arduino_Library (über Bibliotheksverwaltung) https://github.com/sparkfun/SparkFun_SCD30_Arduino_Library
 *  - MH-Z19 by Jonathan Dempsey (über Bibliotheksverwaltung) https://github.com/WifWaf/MH-Z19
 */

#define USE_SCD30
//#define USE_MHZ19


// Replace with your desired network name
const char* ssid = "CO2-Ampel";

// Hardwaresettings
const int ledPinRed = 17;     // Nico: 32
const int ledPinGreen = 12;   // Nico: 33
const int ledPinBlue = 13;    // Nico: 12

const int measurement_interval = 30000; // delay between measurements in ms

const int level_red = 2000;
const int level_yellow = 1500;

// Load Wi-Fi library
#include <WiFi.h>
#include <DNSServer.h>

// for AP mode
const byte DNS_PORT = 53;
IPAddress apIP(192, 168, 1, 1);
DNSServer dnsServer;

// Set web server port number to 80
WiFiServer server(80);

// Variable to store the HTTP request
String header;

#include <Wire.h>
#include <Arduino.h>

#ifdef USE_SCD30
  #include "SparkFun_SCD30_Arduino_Library.h" //Click here to get the library: http://librarymanafger/All#SparkFun_SCD30
  SCD30 airSensor;
#endif


uint16_t co2;
float temperature;
float humidity;

unsigned long time_now;
String color_start;
String color_end;

void setup()
{
  Serial.begin(115200);
  Serial.println("CO2-api: Luftqualität messen, anzeigen und über Wifi oder LoRa weitergeben");

  Wire.begin();

#ifdef USE_SCD30
  if (airSensor.begin() == false)
    {
      Serial.println("Air sensor not detected. Please check wiring. Freezing...");
      while (1)
        ;
    }
#endif
#ifdef USE_MHZ19
  mySerial.begin(BAUDRATE, SERIAL_8N1, RX_PIN, TX_PIN);
  airSensor.begin(mySerial);
  airSensor.autoCalibration(); //auto calibration ON
#endif


  // RGB LED Ports konfigurieren
  pinMode(ledPinRed, OUTPUT);
  pinMode(ledPinGreen, OUTPUT);
  pinMode(ledPinBlue, OUTPUT);

  // Connect to Wi-Fi network with SSID and password
  Serial.print("Setting AP (Access Point)...");

  WiFi.disconnect();   //added to start with the wifi off, avoid crashing
  WiFi.mode(WIFI_OFF); //added to start with the wifi off, avoid crashing
  WiFi.mode(WIFI_AP);
  WiFi.softAPConfig(apIP, apIP, IPAddress(255, 255, 255, 0));
  WiFi.softAP(ssid);

  // if DNSServer is started with "*" for domain name, it will reply with
  // provided IP to all DNS request
  dnsServer.start(DNS_PORT, "*", apIP);

  server.begin();
  time_now = millis()-measurement_interval;
}

void loop()
{
  if (millis() > time_now + measurement_interval)
    {
      time_now=millis();
#ifdef USE_SCD30
      if (airSensor.dataAvailable())
#endif
        {
          co2 = airSensor.getCO2();
          temperature = airSensor.getTemperature();
          humidity = 0;
#ifdef USE_SCD30
          humidity = airSensor.getHumidity();
#endif
        }

      if(co2 > level_red)          // red
        {
          digitalWrite(ledPinRed, HIGH);
          digitalWrite(ledPinGreen, LOW);
          digitalWrite(ledPinBlue, LOW);
          color_start="<red>";
          color_end="</red>";
        }
      else if(co2 > level_yellow)     // yellow
        {
          digitalWrite(ledPinRed, HIGH);
          digitalWrite(ledPinGreen, HIGH);
          digitalWrite(ledPinBlue, LOW);
          color_start="<yellow>";
          color_end="</yellow>";
        }
      else                   // green
        {
          digitalWrite(ledPinRed, LOW);
          digitalWrite(ledPinGreen, HIGH);
          digitalWrite(ledPinBlue, LOW);
          color_start="<green>";
          color_end="</green>";
        }

      Serial.print("co2: ");
      Serial.print(co2);
      Serial.println(" ppm");

      Serial.print("temp: ");
      Serial.print(temperature, 1);
      Serial.println(" °C");

      Serial.print("humidity: ");
      Serial.print(humidity, 1);
      Serial.println(" %");

      Serial.println();
    }

  dnsServer.processNextRequest();

  WiFiClient client = server.available();   // Listen for incoming clients
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

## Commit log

2020-11-13 SCD30 auslesen und über serial und TCP ausgeben
2020-11-14 uuids in sep file, enabled rgb led
2020-11-14 LoRa Server mit ESP32 Module von az-delivery und externem RFM9x Modul
2020-11-14 add case
    [case.scad]
2020-11-14 u8x8 Library GraphicsTest für unser Hiltec LoRa Board mit OLED
2020-11-14 Für Hiltec WiFi LoRa 32 V2. Zeigt SCD30 CO2, Temperatur, rH auf dem Display an
2020-11-14 redesigned case (screw holes)
    [case.scad]
2020-11-14 README, bekanntes Problem mit mehreren I2C Devices
2020-11-14 improvements for case; add back to case
    [case.scad]
2020-11-14 Bugfix '0' vs. '\0' und .gitignore gefixed
    [Lora_WiFi_Bridge.ino]
2020-11-14 adapted LED dia (after print...)
    [case.scad]
2020-11-15 add stl files for case and back plate
    [back.stl, case.stl]
2020-11-15 Uploadordner nach sciebo
    [case.scad]
2020-11-15 sciebo_uplod STL files dazu, 2 Bilder ausgetauscht
    [back.stl, case.stl]
2020-11-15 UUIDs für die Uni zum testen hinzugefügt
2020-11-15 improvements for case
    [case.scad, case.stl]
2020-11-16 rounded corners and some more refinements
    [case.scad]
2020-11-18 Removed redundant upload files
    [back.stl, case.scad, case.stl]
2020-11-18 README:md: Bilder einbinden und nicht realisierte Ideen hinzugefügt
2020-11-19 sqlite und volkszähler gelöscht
2020-11-21 auch die "id" mit als tag speichern
2020-11-21 docker-compose.yml: volume storage für influxdb und grafana
2020-11-22 scripts zur generierung des dashboards verschoben
2020-11-22 docker-compose.yml: Influxdb nur von innerhalb des containers
2020-11-27 SCD30_or_MHZ19_to_nodejs_influxdb: Volkszähler und LoRa entfernt, RSSI Anzeige im Display
2020-11-29 Volkszähler wieder aktiviert, CO2 Grenzwerte von Nico übernommen (in der Tabelle stehen werte reölativ über 400ppm)
2020-12-06 OLED output use fixed width
    [SCD30_or_MHZ19_to_nodejs_influxdb.ino, SCD30_or_MHZ19_to_volkszaehler_LoRa_fallback.ino]
2021-03-15 refine case
    [case.scad]
2021-03-15 update stls
    [back.stl, case.stl]
2021-03-16 adjust holes for usb connector and led
    [case.scad]
2021-03-17 correct back.stl (and case.scad) in size
    [back.stl, case.scad, case.stl]
2021-03-17 cas.scad: Fix Y of one of the back bars
    [case.scad]
2021-03-21 Eine Client Variante ohne WiFi/LoRa hinzugefügt, fix typos in Readme
    [SCD30_or_MHZ19_no_connectivity.ino]
2021-03-21 LED Haube hinzugefügt, wird mit weißem PLA gedruckt
    [LED_Haube.FCStd]
2021-12-19 last change was missing in back.stl
    [back.stl]
